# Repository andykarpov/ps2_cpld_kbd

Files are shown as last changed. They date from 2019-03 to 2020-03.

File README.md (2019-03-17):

# PS/2 AVR CPLD keyboard adapter

PS/2 keyboard adapter for ZX Spectrum on Atmega328 + EPM7128STC100.
Designed to be connected directly instead of a mechanical keyboard.

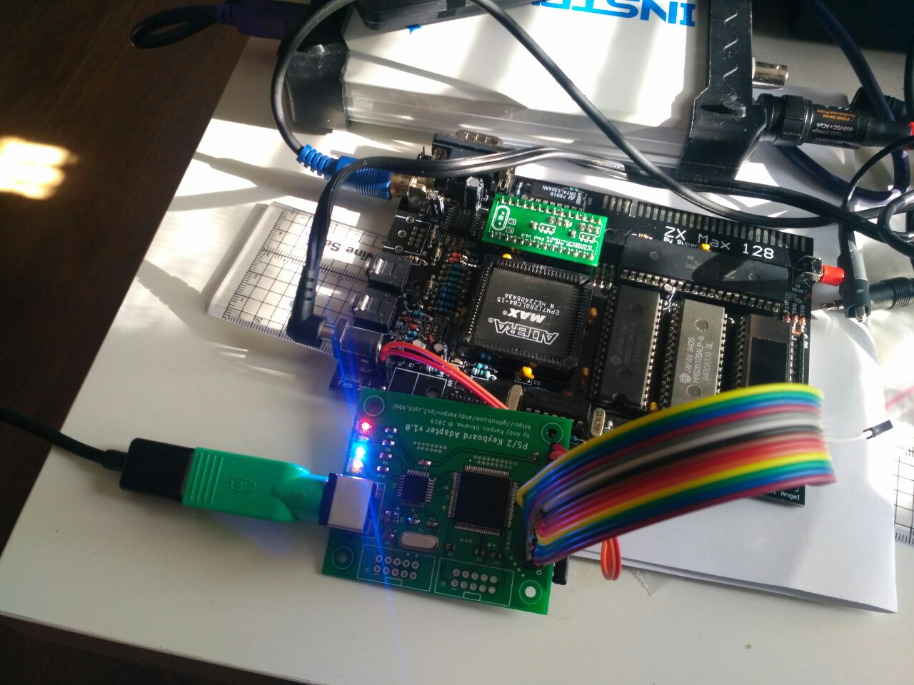
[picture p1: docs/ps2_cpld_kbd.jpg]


Based on the idea of the Yet another ZX-Spectrum AT Keyboard Interface http://www.jrok.com/project/speckey/spec_key.html

## How to program

### Programming Atmega328p
1. disconnect EPM7128 from the power source by disconnecting jumper JP1
2. avrdude -p atmega328p -c USBasp -U flash:w:avr_kbd_mega328p.hex -U lfuse:w:0xbf:m -U hfuse:w:0xda:m -U efuse:w:0xfd:m
3. short JP1

### Programming EPM7128S
use quartus programmer to flash cpld_kbd.pof

## Available hotkeys
1. Ctrl+Alt+Del generate a short negative pulse on O_RESET pin. It's nice to connect this signal to N_RESET of your ZX Spectrum
2. Ctrl+Alt+Backspace produce a controller internal reset needed for some reason
3. F2 generate a short negative pulse on O_MAGICK pin. If you have a BDI controller then you have to connect this signal to magick button.
4. Scroll Lock switch on / off the O_TURBO signal
5. PrintScreen switch on / off the O_SPECIAL signal

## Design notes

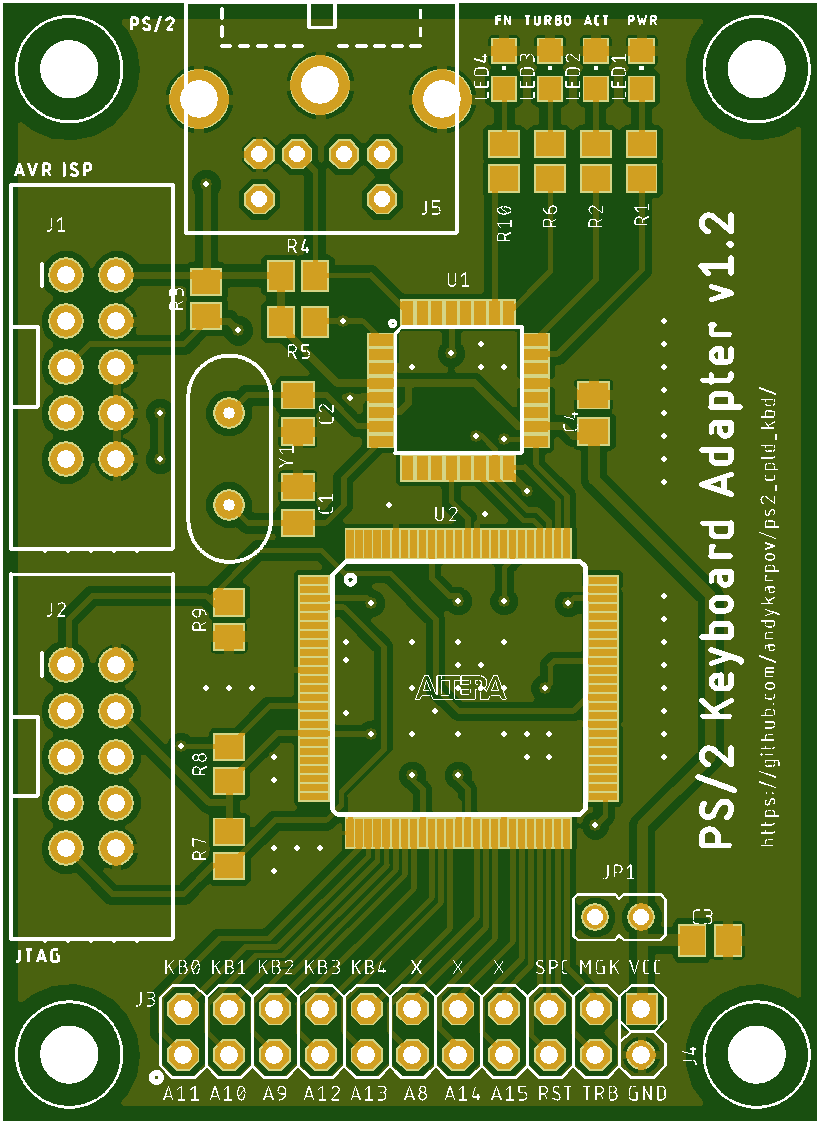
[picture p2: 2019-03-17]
docs/ps2_cpld_kbd_1.2.png

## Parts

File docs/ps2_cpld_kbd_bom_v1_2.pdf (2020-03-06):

Sheet1

Component | Quantity | Package | Value
U1 | 1 | QFP-32 | Atmega328P-AU
U2 | 1 | TQFP-100 | EPM7128STC100-15N
Y1 | 1 | HC-49S | 16.000 MHz crysyal
R3,R11-R18 | 9 | R 0805 | 10k
R1,R2,R6,R10 | 4 | R 0805 | 470 Ohm
R7,R8,R9 | 3 | R 0805 | 1k
R4,R5 | 2 | R 0805 | 4k7
C1,C2 | 2 | C 0805 | 22pF
C3-C8 | 6 | C 0805 | 100nF
LED1-LED4 | 4 | LED 0805 | red,green,yellow,blue,etc
J5 | 1 | Mini-DIN6 (ps/2 female socket)
J1,J2 | 2 | 10p IDC male Shrouded Header
J3 | 1 | 20p Pin Header (0.1”)
J4, JP1 | 2 | 2p Pin Header (0.1”)

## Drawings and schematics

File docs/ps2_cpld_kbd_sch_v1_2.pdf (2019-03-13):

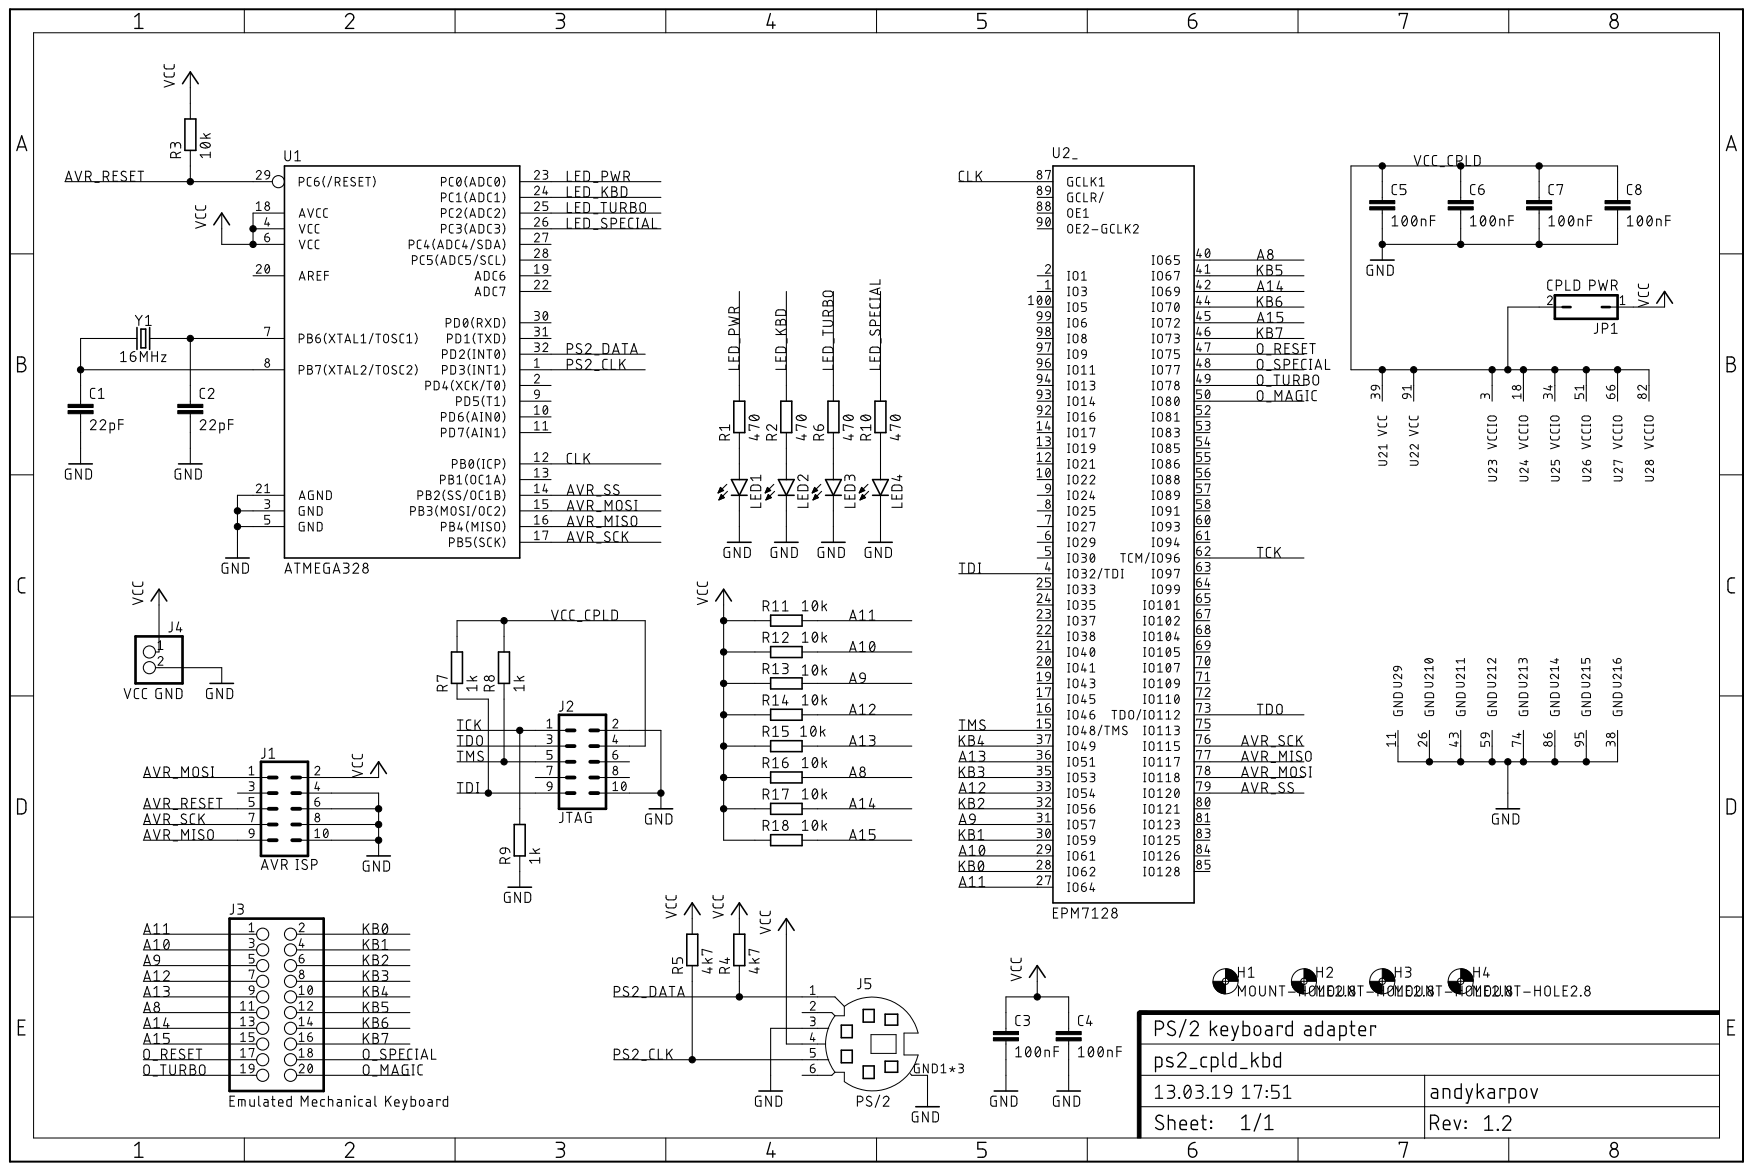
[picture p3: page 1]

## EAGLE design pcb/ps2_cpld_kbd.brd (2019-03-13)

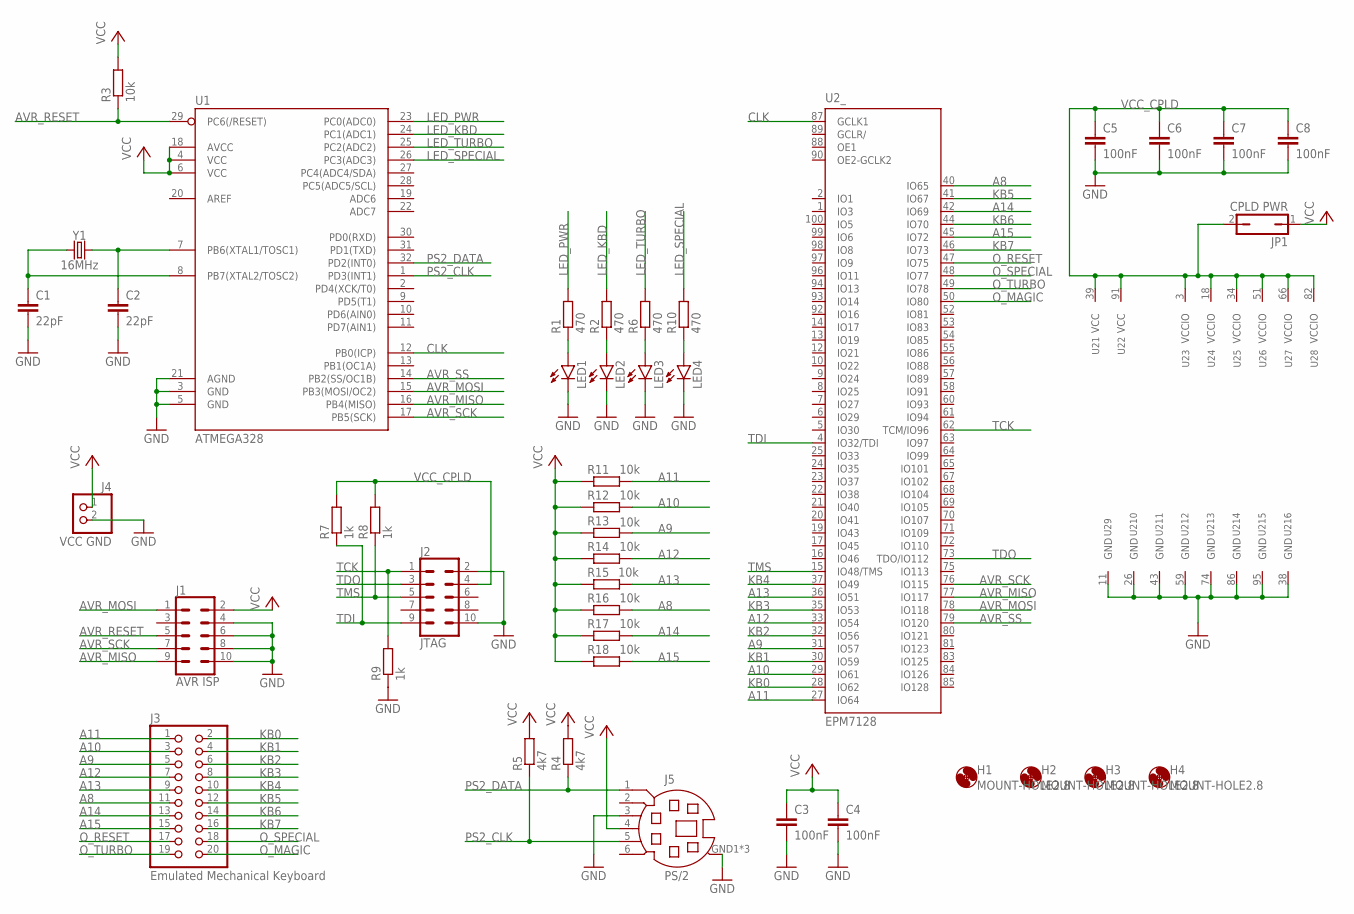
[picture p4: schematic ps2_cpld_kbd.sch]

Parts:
C1, C2: 22pF; C0805K
C3, C4, C5, C6, C7, C8: 100nF; C0805K
H1, H2, H3, H4: MOUNT-HOLE2.8; 2,8
J1: AVR ISP; 2X5-SHROUDED_LOCK
J2: JTAG; 2X5-SHROUDED_LOCK
J3: Emulated Mechanical Keyboard; 2X10
J4: VCC GND; 1X02
J5: PS/2; MDIN06SS
JP1: CPLD PWR; JP1
LED1, LED2, LED3, LED4: LEDCHIPLED_0805; CHIPLED_0805
R1, R2, R6, R10: 470; R0805
R3, R11, R12, R13, R14, R15, R16, R17, R18: 10k; R0805
R4, R5: 4k7; R0805
R7, R8, R9: 1k; R0805
U1: ATMEGA328; TQFP32-08
U2: EPM7128; TQFP100
Y1: 16MHz; HC49US

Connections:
A8: J3.11, R16.2, U2.40 (IO65)
A9: J3.5, R13.2, U2.31 (IO57)
A10: J3.3, R12.2, U2.29 (IO61)
A11: J3.1, R11.2, U2.27 (IO64)
A12: J3.7, R14.2, U2.33 (IO54)
A13: J3.9, R15.2, U2.36 (IO51)
A14: J3.13, R17.2, U2.42 (IO69)
A15: J3.15, R18.2, U2.45 (IO72)
AVR_MISO: J1.9, U1.16 (PB4(MISO)), U2.77 (IO117)
AVR_MOSI: J1.1, U1.15 (PB3(MOSI/OC2)), U2.78 (IO118)
AVR_RESET: J1.5, R3.1, U1.29 (PC6(/RESET))
AVR_SCK: J1.7, U1.17 (PB5(SCK)), U2.76 (IO115)
AVR_SS: U1.14 (PB2(SS/OC1B)), U2.79 (IO120)
CLK: U1.12 (PB0(ICP)), U2.87 (GCLK1)
GND: C1.2, C2.2, C3.2, C4.2, C5.2, C6.2, C7.2, C8.2, J1.4, J1.6, J1.8, J1.10, J2.2, J2.10, J4.2, J5.3, J5.GND1 (GND), J5.GND2 (GND), J5.GND3 (GND), LED1.C, LED2.C, LED3.C, LED4.C, R9.1, U1.3 (GND), U1.5 (GND), U1.21 (AGND), U2.11 (GND), U2.26 (GND), U2.38 (GND), U2.43 (GND), U2.59 (GND), U2.74 (GND), U2.86 (GND), U2.95 (GND)
KB0: J3.2, U2.28 (IO62)
KB1: J3.4, U2.30 (IO59)
KB2: J3.6, U2.32 (IO56)
KB3: J3.8, U2.35 (IO53)
KB4: J3.10, U2.37 (IO49)
KB5: J3.12, U2.41 (IO67)
KB6: J3.14, U2.44 (IO70)
KB7: J3.16, U2.46 (IO73)
LED_KBD: R2.2, U1.24 (PC1(ADC1))
LED_PWR: R1.2, U1.23 (PC0(ADC0))
LED_SPECIAL: R10.2, U1.26 (PC3(ADC3))
LED_TURBO: R6.2, U1.25 (PC2(ADC2))
unnamed: LED3.A, R6.1
unnamed: LED2.A, R2.1
unnamed: LED1.A, R1.1
unnamed: C2.1, U1.7 (PB6(XTAL1/TOSC1)), Y1.2
unnamed: C1.1, U1.8 (PB7(XTAL2/TOSC2)), Y1.1
unnamed: LED4.A, R10.1
O_MAGIC: J3.20, U2.50 (IO80)
O_RESET: J3.17, U2.47 (IO75)
O_SPECIAL: J3.18, U2.48 (IO77)
O_TURBO: J3.19, U2.49 (IO78)
PS2_CLK: J5.5, R5.1, U1.1 (PD3(INT1))
PS2_DATA: J5.1, R4.1, U1.32 (PD2(INT0))
TCK: J2.1, R9.2, U2.62 (TCM/IO96)
TDI: J2.9, R7.1, U2.4 (IO32/TDI)
TDO: J2.3, U2.73 (TDO/IO112)
TMS: J2.5, R8.1, U2.15 (IO48/TMS)
VCC: C3.1, C4.1, J1.2, J4.1, J5.4, JP1.1, R3.2, R4.2, R5.2, R11.1, R12.1, R13.1, R14.1, R15.1, R16.1, R17.1, R18.1, U1.4 (VCC), U1.6 (VCC), U1.18 (AVCC)
VCC_CPLD: C5.1, C6.1, C7.1, C8.1, J2.4, JP1.2, R7.2, R8.2, U2.3 (VCCIO), U2.18 (VCCIO), U2.34 (VCCIO), U2.39 (VCC), U2.51 (VCCIO), U2.66 (VCCIO), U2.82 (VCCIO), U2.91 (VCC)

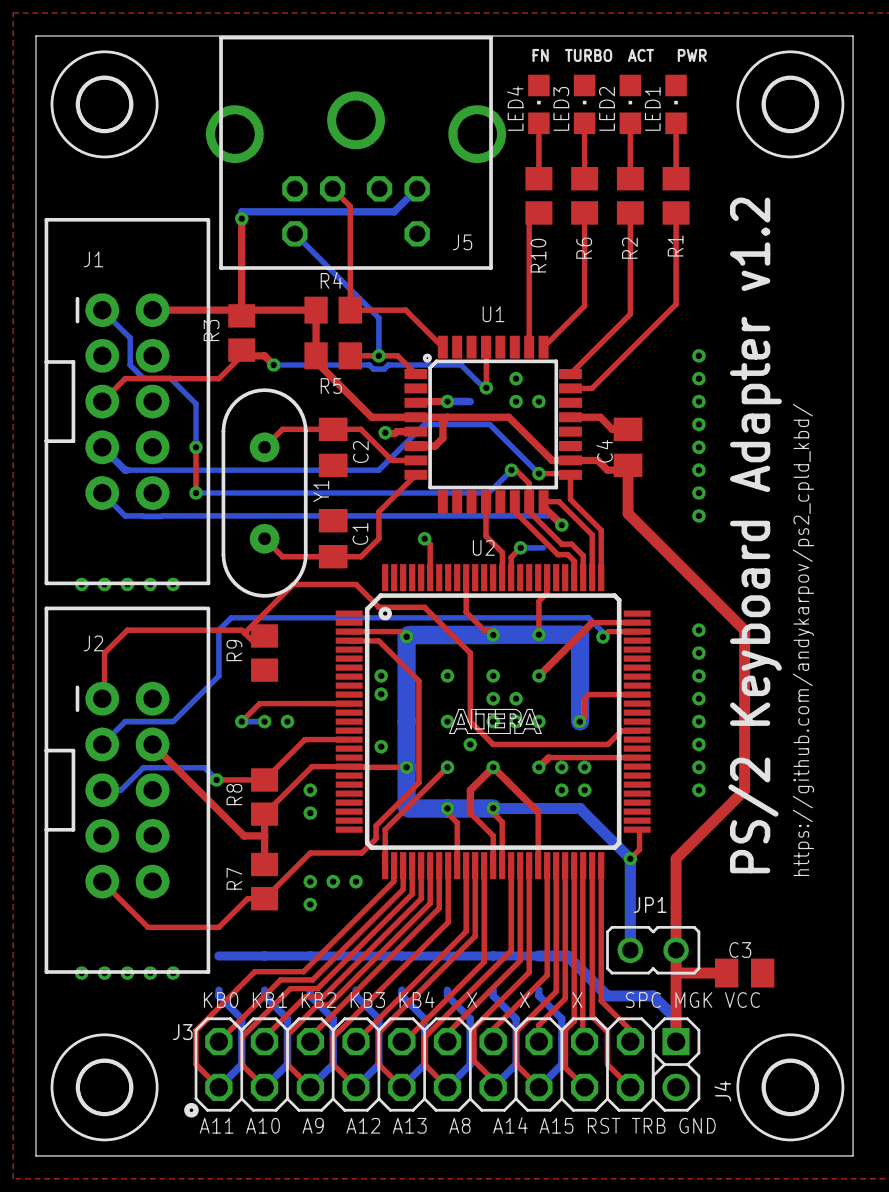
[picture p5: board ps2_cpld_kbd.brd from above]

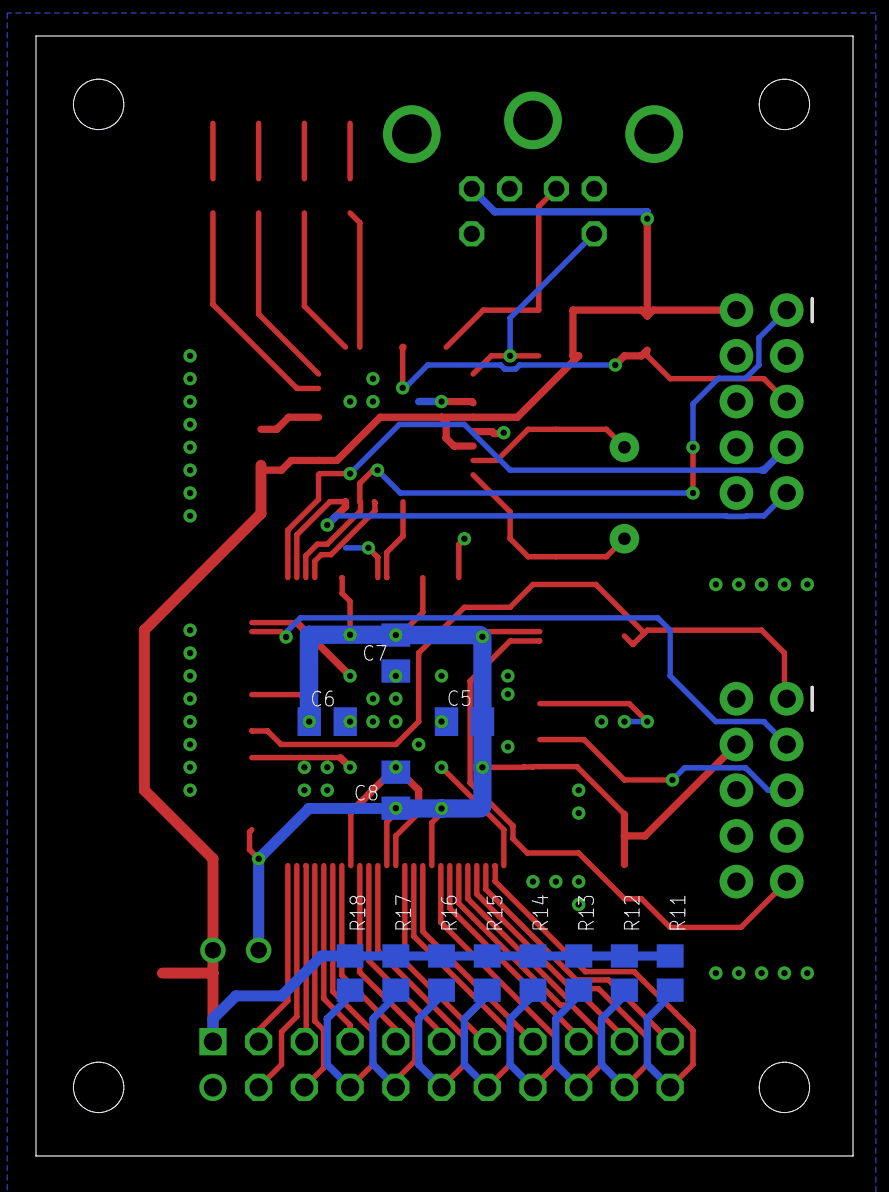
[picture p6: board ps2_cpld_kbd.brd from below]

Board: 2 copper layers, 45.4 x 62.2 mm, 43 parts (12 on the bottom side), 45 nets.

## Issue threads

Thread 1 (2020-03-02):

BoM list please

jduraes, 2020-03-02:
Hi Andy,

Any chance you could please publish a Bill of Materials for the components used? I know I could decipher them, but I'm learning and didn't want to make mistakes. Thanks.

andykarpov, 2020-03-06:
Ok, will try to do that

andykarpov, 2020-03-06:
Done: https://github.com/andykarpov/ps2_cpld_kbd/raw/master/docs/ps2_cpld_kbd_bom_v1_2.pdf

Closed 2020-03-06.

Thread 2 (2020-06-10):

Powering up

mr-mosh, 2020-06-10:
@andykarpov , sorry to trouble you this way, but I don't have any other means to contact you.

I have now built the adapter with the v1.2 files, and I have a few questions please:

- Is it normal for the Altera Max to sometimes fail on programming? I have never programmed an FPGA before. In the end I succeeded, but it took a few attempts - like, literally just pressing "Program" a few times until it worked.
- What's the best way to test the adapter, before I plug it into my 48k Spectrum? Cross check the matrix while pressing keys on the PS/2 keyboard?
- Am I right in saying that JP1 is just an on/off switch for the CPLD?
- Should I power the adapter using J4 (VCC/GND)?
- What's the right voltage to use? 3.3v seems to work, but a default 48k Spectrum only has 5v (well, and -5v, 9v and 12v...)
- Any idea how to power it from a Spectrum 48k? Do I just pull some VCC from anywhere, or should it be tied into something in particular?
- In your case you've used a ZX Max 128 as an example, so I don't have a reference to go for. For example, you have wires from JP1 to the ZX Max - does the ZX Max switch it on by some function on it? Or is it actually powering the adapter using those wires?

Many thanks - I had fun building it. Now hoping to actually use it! :-)

P.S.: is there a way for me to get the ZX Max 128? I would love to build that my next project. Cheers.

andykarpov, 2020-06-10:
@mr-mosh, congratulations and thanks for a lot of questions! :)
Will try to answer them:
1) Altera sometimes fails on programming - i think it's not very good, probably depends on the power quality applied to the altera while programming it. Did you applied 5V to the adapter while programmming it?
2) No ideas about the best way to test the adapter, really. You can apply power to it and connect a ps/2 keyboard and see if leds are blinked while pressing the keys, etc. The keyboard data will be available on the KB0-KB4 lines only in case one of the A8-A15 lines is LOW and some keys is pressed. So, i think you can try to ground some address pin and test it this way.
3) Yes, JP1 is just to on/off the power from the CPLD. Because it's hard connected to the AVR via the SPI, the same pins used to to program the AVR.
4) Yes, you need to power your adapter via J4 (VCC/GND). There is should be 5V DC.
5) You can grab 5V and GND somewhere from the Speccy 48k board, like from the CPU, for example :)
6) There was no JP1 on the v1.0 of the adapter, so it's unclear a bit what is your question about the ZX Max ;) Probably you mean a J4 ? So then - yes, it's just for powering the adapter by that connector.
7) Anyway, if the altera and atmega was successfully flashed - feel free to try it with the real hardware.

P.S. I think you can check on eBay, on the speccy.pl forum or on the chipkin.ru website for the clean PCB of ZX Max 128. For example: https://chipkin.ru/product/pechatnaya-plata-zx-max128/

Good luck, @mr-mosh! You can PM me to andy.karpov+github at gmail.com

andykarpov, 2020-06-17:
@mr-mosh, any news/questions ?

mr-mosh, 2020-06-17:
Hi @andykarpov ,

I do have them, but have been leaving some time before my next barrage of questions. :-)

Just kidding. I had to focus on something else and didn't have the will to get back to it.

This because it didn't quite work. All I was getting when pressing some of the keys, mostly on the left side of the keyboard, was the character "c" being registered on the Spectrum, and with about some 200ms delay (is that the expect lag?).

I don't know if the problem is on the adapter itself, or actually on the Spectrum. This Issue 4B board was in really bad shape and I had to reconstruct a lot of the traces to the CPU, memory, ULA, and also had to replace some resistors and diodes. I have not yet recapped it either.

But there are a lot of things that need re-checking, which is why I said I need more time to debug it in detail. I also made some mistakes on the adapter. I initially used some very old solder, and that didn't flow properly over the CPLD, and then I made a nasty job cleaning it up, damaging some pads in the process. The EPM7128 I've used also didn't have pin 1 on it, although I don't think that matters, as pin 1 on your schematic isn't connected to anything - right?

I've ordered some new EPM7128s to try it on a new, fresh PCB. Coincidently, they have just arrived today. Question: does it matter that they're 100ns instead of the 150ns you've used? Usually faster is better, right? Famous last words... :-)

I'm going to get back to it on Friday, and I think I'll first try the adapter with a known-good Spectrum - I have a "good" Issue 4S where I have also used pins for the keyboard connectors, so I can try it there. Then I'll know if the problem is with the Spectrum or the adapter. If the adapter, I'll build a new one; if the Spectrum, well, I'll have a lot of fun troubleshooting on that front...

Following on from our previous stable 5v talk, I've used a good 5v source and was still have random success re-programming the CPLD: sometimes it worked, sometimes it didn't. So I'm not even sure if the CPLD was programmed successfully or not.

Anyway, I'll look at it again on Friday and let you know.

Cheers.

andykarpov, 2020-06-17:
Hmm, well, something seems wrong. 200ms delay is not the expected thing at all ;)

How did you flashed the AVR ? Does the fuse bits are flashed ok ? Because i used it's feature CKOUT to out a 16MHz clock to the CPLD.

Altera's PIN_1 is ok to be unconnected ;)

100ns / 150ns - does not matter, they all should work.

Does the A and KB lines are connected properly to the speccy?

Regarding the partial success with CPLD programming - that's really strange, i think it's because of bad soldering of some I/O power lines on it.

Anyway - good luck with rework on a new PCB with a new solder ;)

P.S. Did you tried it with another keyboard?

IvanKoc87, 2022-02-09:
Можно заменить атмегу 328 на атмегу 8 ?

andykarpov, 2022-02-09:
> Можно заменить атмегу 328 на атмегу 8 ?

нельзя, она не умеет делать CKOUT (клок для тактирования CPLD).
можно попробовать заменить на atmega 168.

IvanKoc87, 2022-02-09:
можно попробовать заменить на atmega 168.
Смысла нет у них цена одинакова.

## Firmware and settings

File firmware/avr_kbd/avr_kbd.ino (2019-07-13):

/*
 * AVR keyboard firmware for ps2_cpld_kbd project
 * 
 * Designed to build on Arduino IDE.
 * 
 * @author Andy Karpov <andy.karpov@gmail.com>
 * Ukraine, 2019
 */

#include "ps2.h"
#include "matrix.h"
#include "ps2_codes.h"
#include <EEPROM.h>
#include <SPI.h>

#define DEBUG_MODE 0

// ---- Pins for Atmega328
#define PIN_KBD_CLK 3 // PD2
#define PIN_KBD_DAT 2 // PD2

// hardware SPI
#define PIN_SS 10 // SPI slave select

#define LED_PWR A0
#define LED_KBD A1
#define LED_TURBO A2
#define LED_SPECIAL A3

#define EEPROM_TURBO_ADDRESS 0x00
#define EEPROM_SPECIAL_ADDRESS 0x01

#define EEPROM_VALUE_TRUE 10
#define EEPROM_VALUE_FALSE 20

PS2KeyRaw kbd;

bool matrix[ZX_MATRIX_FULL_SIZE]; // matrix of pressed keys + special keys to be transmitted on CPLD side by SPI protocol

bool blink_state = false;

bool is_turbo = false;
bool is_special = false;

unsigned long t = 0;  // current time
unsigned long tl = 0; // blink poll time
unsigned long te = 0; // eeprom store time

SPISettings settingsA(8000000, MSBFIRST, SPI_MODE0); // SPI transmission settings

// transform PS/2 scancodes into internal matrix of pressed keys
void fill_kbd_matrix(int sc)
{

  static bool is_up=false, is_e=false, is_e1=false;
  static bool is_ctrl=false, is_alt=false, is_del=false, is_bksp = false, is_shift = false, is_esc = false, is_ss_used = false, is_cs_used = false;

  // is extended scancode prefix
  if (sc == 0xE0) {
    is_e = 1;
    return;
  }

 if (sc == 0xE1) {
    is_e = 1;
    is_e1 = 1;
    return;
  }

  // is key released prefix
  if (sc == 0xF0 && !is_up) {
    is_up = 1;
    return;
  }

  int scancode = sc + ((is_e || is_e1) ? 0x100 : 0);

  is_ss_used = false;
  is_cs_used = false;

  switch (scancode) {
  
    // Shift -> CS for ZX
    case PS2_L_SHIFT: 
    case PS2_R_SHIFT:
      matrix[ZX_K_CS] = !is_up;
      is_shift = !is_up;
      break;

    // Ctrl -> SS for ZX
    case PS2_L_CTRL:
    case PS2_R_CTRL:
      matrix[ZX_K_SS] = !is_up;
      is_ctrl = !is_up;
      break;

    // Alt (L) -> SS+CS for ZX
    case PS2_L_ALT:
      matrix[ZX_K_SS] = !is_up;
      matrix[ZX_K_CS] = !is_up;
      is_alt = !is_up;
      is_cs_used = !is_up;
      break;

    // Alt (R) -> SS+CS for ZX
    case PS2_R_ALT:
      matrix[ZX_K_SS] = !is_up;
      matrix[ZX_K_CS] = !is_up;
      is_alt = !is_up;
      is_cs_used = !is_up;
      break;

    // Del -> SS+C for ZX
    case PS2_DELETE:
       matrix[ZX_K_SS] = !is_up;
       matrix[ZX_K_C] =  !is_up;
      is_del = !is_up;
    break;

    // Ins -> SS+A for ZX
    case PS2_INSERT:
       matrix[ZX_K_SS] = !is_up;
       matrix[ZX_K_A] =  !is_up;
    break;

    // Cursor -> CS + 5,6,7,8
    case PS2_UP:
      matrix[ZX_K_CS] = !is_up;
      matrix[ZX_K_7] = !is_up;
      is_cs_used = !is_up;
      break;
    case PS2_DOWN:
      matrix[ZX_K_CS] = !is_up;
      matrix[ZX_K_6] = !is_up;
      is_cs_used = !is_up;
      break;
    case PS2_LEFT:
      matrix[ZX_K_CS] = !is_up;
      matrix[ZX_K_5] = !is_up;
      is_cs_used = !is_up;
      break;
    case PS2_RIGHT:
      matrix[ZX_K_CS] = !is_up;
      matrix[ZX_K_8] = !is_up;
      is_cs_used = !is_up;
      break;

    // ESC -> CS+SPACE for ZX
    case PS2_ESC:
      matrix[ZX_K_CS] = !is_up;
      matrix[ZX_K_SP] = !is_up;
      is_cs_used = !is_up;
      is_esc = !is_up;
      break;

    // Backspace -> CS+0
    case PS2_BACKSPACE:
      matrix[ZX_K_CS] = !is_up;
      matrix[ZX_K_0] = !is_up;
      is_cs_used = !is_up;
      is_bksp = !is_up;
      break;

    // Enter
    case PS2_ENTER:
    case PS2_KP_ENTER:
      matrix[ZX_K_ENT] = !is_up;
      break;

    // Space
    case PS2_SPACE:
      matrix[ZX_K_SP] = !is_up;
      break;

    // Letters & numbers
    case PS2_A: matrix[ZX_K_A] = !is_up; break;
    case PS2_B: matrix[ZX_K_B] = !is_up; break;
    case PS2_C: matrix[ZX_K_C] = !is_up; break;
    case PS2_D: matrix[ZX_K_D] = !is_up; break;
    case PS2_E: matrix[ZX_K_E] = !is_up; break;
    case PS2_F: matrix[ZX_K_F] = !is_up; break;
    case PS2_G: matrix[ZX_K_G] = !is_up; break;
    case PS2_H: matrix[ZX_K_H] = !is_up; break;
    case PS2_I: matrix[ZX_K_I] = !is_up; break;
    case PS2_J: matrix[ZX_K_J] = !is_up; break;
    case PS2_K: matrix[ZX_K_K] = !is_up; break;
    case PS2_L: matrix[ZX_K_L] = !is_up; break;
    case PS2_M: matrix[ZX_K_M] = !is_up; break;
    case PS2_N: matrix[ZX_K_N] = !is_up; break;
    case PS2_O: matrix[ZX_K_O] = !is_up; break;
    case PS2_P: matrix[ZX_K_P] = !is_up; break;
    case PS2_Q: matrix[ZX_K_Q] = !is_up; break;
    case PS2_R: matrix[ZX_K_R] = !is_up; break;
    case PS2_S: matrix[ZX_K_S] = !is_up; break;
    case PS2_T: matrix[ZX_K_T] = !is_up; break;
    case PS2_U: matrix[ZX_K_U] = !is_up; break;
    case PS2_V: matrix[ZX_K_V] = !is_up; break;
    case PS2_W: matrix[ZX_K_W] = !is_up; break;
    case PS2_X: matrix[ZX_K_X] = !is_up; break;
    case PS2_Y: matrix[ZX_K_Y] = !is_up; break;
    case PS2_Z: matrix[ZX_K_Z] = !is_up; break;

    // digits
    case PS2_0: matrix[ZX_K_0] = !is_up; break;
    case PS2_1: matrix[ZX_K_1] = !is_up; break;
    case PS2_2: matrix[ZX_K_2] = !is_up; break;
    case PS2_3: matrix[ZX_K_3] = !is_up; break;
    case PS2_4: matrix[ZX_K_4] = !is_up; break;
    case PS2_5: matrix[ZX_K_5] = !is_up; break;
    case PS2_6: matrix[ZX_K_6] = !is_up; break;
    case PS2_7: matrix[ZX_K_7] = !is_up; break;
    case PS2_8: matrix[ZX_K_8] = !is_up; break;
    case PS2_9: matrix[ZX_K_9] = !is_up; break;

    // Keypad digits
    case PS2_KP_0: matrix[ZX_K_0] = !is_up; break;
    case PS2_KP_1: matrix[ZX_K_1] = !is_up; break;
    case PS2_KP_2: matrix[ZX_K_2] = !is_up; break;
    case PS2_KP_3: matrix[ZX_K_3] = !is_up; break;
    case PS2_KP_4: matrix[ZX_K_4] = !is_up; break;
    case PS2_KP_5: matrix[ZX_K_5] = !is_up; break;
    case PS2_KP_6: matrix[ZX_K_6] = !is_up; break;
    case PS2_KP_7: matrix[ZX_K_7] = !is_up; break;
    case PS2_KP_8: matrix[ZX_K_8] = !is_up; break;
    case PS2_KP_9: matrix[ZX_K_9] = !is_up; break;

    // '/" -> SS+P / SS+7
    case PS2_QUOTE:
      matrix[ZX_K_SS] = !is_up;
      matrix[is_shift ? ZX_K_P : ZX_K_7] = !is_up;
      is_ss_used = is_shift;
      break;

    // ,/< -> SS+N / SS+R
    case PS2_COMMA:
      matrix[ZX_K_SS] = !is_up;
      matrix[is_shift ? ZX_K_R : ZX_K_N] = !is_up;
      is_ss_used = is_shift;
      break;

    // ./> -> SS+M / SS+T
    case PS2_PERIOD:
    case PS2_KP_PERIOD:
      matrix[ZX_K_SS] = !is_up;
      matrix[is_shift ? ZX_K_T : ZX_K_M] = !is_up;
      is_ss_used = is_shift;
      break;

    // ;/: -> SS+O / SS+Z
    case PS2_SEMICOLON:
      matrix[ZX_K_SS] = !is_up;
      matrix[is_shift ? ZX_K_Z : ZX_K_O] = !is_up;
      is_ss_used = is_shift;
      break;

    // [,{ -> SS+Y / SS+F
    case PS2_L_BRACKET:
      if (!is_up) {
        send_macros(is_shift ? ZX_K_F : ZX_K_Y);
      }
      break;

    // ],} -> SS+U / SS+G
    case PS2_R_BRACKET:
      if (!is_up) {
        send_macros(is_shift ? ZX_K_G : ZX_K_U);
      }
      break;

    // /,? -> SS+V / SS+C
    case PS2_SLASH:
    case PS2_KP_SLASH:
      matrix[ZX_K_SS] = !is_up;
      matrix[is_shift ? ZX_K_C : ZX_K_V] = !is_up;
      is_ss_used = is_shift;
      break;

    // \,| -> SS+D / SS+S
    case PS2_BACK_SLASH:
      if (!is_up) {
        send_macros(is_shift ? ZX_K_S : ZX_K_D);
      }
      break;

    // =,+ -> SS+L / SS+K
    case PS2_EQUALS:
      matrix[ZX_K_SS] = !is_up;
      matrix[is_shift ? ZX_K_K : ZX_K_L] = !is_up;
      is_ss_used = is_shift;
      break;

    // -,_ -> SS+J / SS+0
    case PS2_MINUS:
      matrix[ZX_K_SS] = !is_up;
      matrix[is_shift ? ZX_K_0 : ZX_K_J] = !is_up;
      is_ss_used = is_shift;
      break;

    // `,~ -> SS+X / SS+A
    case PS2_ACCENT:
      if (is_shift and !is_up) {
        send_macros(is_shift ? ZX_K_A : ZX_K_X);
      }
      if (!is_shift) {
        matrix[ZX_K_SS] = !is_up;
        matrix[ZX_K_X] = !is_up;
        is_ss_used = is_shift;
      }
      break;

    // Keypad * -> SS+B
    case PS2_KP_STAR:
      matrix[ZX_K_SS] = !is_up;
      matrix[ZX_K_B] = !is_up;
      break;

    // Keypad - -> SS+J
    case PS2_KP_MINUS:
      matrix[ZX_K_SS] = !is_up;
      matrix[ZX_K_J] = !is_up;
      break;

    // Keypad + -> SS+K
    case PS2_KP_PLUS:
      matrix[ZX_K_SS] = !is_up;
      matrix[ZX_K_K] = !is_up;
      break;

    // Tab
    case PS2_TAB:
      matrix[ZX_K_CS] = !is_up;
      matrix[ZX_K_I] = !is_up;
      is_cs_used = !is_up;
      break;

    // CapsLock
    case PS2_CAPS:
      matrix[ZX_K_SS] = !is_up;
      matrix[ZX_K_CS] = !is_up;
      is_cs_used = !is_up;
      break;

    // PgUp -> CS+3 for ZX
    case PS2_PGUP:
      matrix[ZX_K_CS] = !is_up;
      matrix[ZX_K_3] = !is_up;
      is_cs_used = !is_up;
      break;

    // PgDn -> CS+4 for ZX
    case PS2_PGDN:
      matrix[ZX_K_CS] = !is_up;
      matrix[ZX_K_4] = !is_up;
      is_cs_used = !is_up;
      break;

    // Scroll Lock -> Turbo
    case PS2_SCROLL: 
      if (is_up) {
        is_turbo = !is_turbo;        
        eeprom_store_value(EEPROM_TURBO_ADDRESS, is_turbo);
        matrix[ZX_K_TURBO] = is_turbo;
      }
    break;

    // PrintScreen -> Special
    case PS2_PSCR1: 
      if (is_up) {
        is_special = !is_special;        
        eeprom_store_value(EEPROM_SPECIAL_ADDRESS, is_special);
        matrix[ZX_K_SPECIAL] = is_special;
      }
    break;

    // F2 -> Magick button
    case PS2_F2:
      if (is_up) {
        do_magick();
      }
    break;
  
  }

  if (is_ss_used and !is_cs_used) {
      matrix[ZX_K_CS] = false;
  }

  // Ctrl+Alt+Del -> RESET
  if (is_ctrl && is_alt && is_del) {
    is_ctrl = false;
    is_alt = false;
    is_del = false;
    is_shift = false;
    is_ss_used = false;
    is_cs_used = false;
    do_reset();
  }

  // Ctrl+Alt+Bksp -> REINIT controller
  if (is_ctrl && is_alt && is_bksp) {
      is_ctrl = false;
      is_alt = false;
      is_bksp = false;
      is_shift = false;
      is_ss_used = false;
      is_cs_used = false;
      clear_matrix(ZX_MATRIX_SIZE);
      matrix[ZX_K_RESET] = true;
      transmit_keyboard_matrix();
      matrix[ZX_K_S] = true;
      transmit_keyboard_matrix();
      delay(500);
      matrix[ZX_K_RESET] = false;
      transmit_keyboard_matrix();
      delay(500);
      matrix[ZX_K_S] = false;
  }

   // clear flags
   is_up = 0;
   if (is_e1) {
    is_e1 = 0;
   } else {
     is_e = 0;
   }
}

uint8_t get_matrix_byte(uint8_t pos)
{
  uint8_t result = 0;
  for (uint8_t i=0; i<8; i++) {
    uint8_t k = pos*8 + i;
    if (k < ZX_MATRIX_FULL_SIZE) {
      bitWrite(result, i, matrix[k]);
    }
  }
  return result;
}

void spi_send(uint8_t addr, uint8_t data) 
{
      SPI.beginTransaction(settingsA);
      digitalWrite(PIN_SS, LOW);
      uint8_t cmd = SPI.transfer(addr); // command (1...6)
      uint8_t res = SPI.transfer(data); // data byte
      digitalWrite(PIN_SS, HIGH);
      SPI.endTransaction();
}

// transmit keyboard matrix from AVR to CPLD side via SPI
void transmit_keyboard_matrix()
{
    uint8_t bytes = 6;
    for (uint8_t i=0; i<bytes; i++) {
      uint8_t data = get_matrix_byte(i);
      spi_send(i+1, data);
    }
}

// transmit keyboard macros (sequence of keyboard clicks) to emulate typing some special symbols [, ], {, }, ~, |, `
void send_macros(uint8_t pos)
{
  clear_matrix(ZX_MATRIX_SIZE);
  transmit_keyboard_matrix();
  delay(20);
  matrix[ZX_K_CS] = true;
  transmit_keyboard_matrix();
  delay(20);
  matrix[ZX_K_SS] = true;
  transmit_keyboard_matrix();
  delay(20);
  matrix[ZX_K_SS] = false;
  transmit_keyboard_matrix();
  delay(20);
  matrix[pos] = true;
  transmit_keyboard_matrix();
  delay(20);
  matrix[ZX_K_CS] = false;
  matrix[pos] = false;
  transmit_keyboard_matrix();
  delay(20);
}

void do_reset()
{
  clear_matrix(ZX_MATRIX_SIZE);
  matrix[ZX_K_RESET] = true;
  transmit_keyboard_matrix();
  delay(500);
  matrix[ZX_K_RESET] = false;
  transmit_keyboard_matrix();  
}

void do_magick()
{
  matrix[ZX_K_MAGICK] = true;
  transmit_keyboard_matrix();
  delay(500);
  matrix[ZX_K_MAGICK] = false;
  transmit_keyboard_matrix();
}

void clear_matrix(int clear_size)
{
    // all keys up
  for (int i=0; i<clear_size; i++) {
      matrix[i] = false;
  }
}

bool eeprom_restore_value(int addr, bool default_value)
{
  byte val;  
  val = EEPROM.read(addr);
  if ((val == EEPROM_VALUE_TRUE) || (val == EEPROM_VALUE_FALSE)) {
    return (val == EEPROM_VALUE_TRUE) ? true : false;
  } else {
    EEPROM.update(addr, (default_value ? EEPROM_VALUE_TRUE : EEPROM_VALUE_FALSE));
    return default_value;
  }
}

void eeprom_store_value(int addr, bool value)
{
  byte val = (value ? EEPROM_VALUE_TRUE : EEPROM_VALUE_FALSE);
  EEPROM.update(addr, val);
}

void eeprom_restore_values()
{
  is_turbo = eeprom_restore_value(EEPROM_TURBO_ADDRESS, is_turbo);
  is_special = eeprom_restore_value(EEPROM_SPECIAL_ADDRESS, is_special);
  matrix[ZX_K_TURBO] = is_turbo;
  matrix[ZX_K_SPECIAL] = is_special;
}

void eeprom_store_values()
{
  eeprom_store_value(EEPROM_TURBO_ADDRESS, is_turbo);
  eeprom_store_value(EEPROM_SPECIAL_ADDRESS, is_special);
}

// initial setup
void setup()
{
  Serial.begin(115200);
  Serial.flush();
  SPI.begin();

  pinMode(PIN_SS, OUTPUT);
  digitalWrite(PIN_SS, HIGH);

  pinMode(LED_PWR, OUTPUT);
  pinMode(LED_KBD, OUTPUT);
  pinMode(LED_TURBO, OUTPUT);
  pinMode(LED_SPECIAL, OUTPUT);
  
  digitalWrite(LED_PWR, HIGH);
  digitalWrite(LED_KBD, HIGH);
  digitalWrite(LED_TURBO, LOW);
  digitalWrite(LED_SPECIAL, LOW);

  // ps/2

  pinMode(PIN_KBD_CLK, INPUT_PULLUP);
  pinMode(PIN_KBD_DAT, INPUT_PULLUP);

  // zx signals (output)

  // clear full matrix
  clear_matrix(ZX_MATRIX_FULL_SIZE);

  // restore saved modes from EEPROM
  eeprom_restore_values();

  digitalWrite(LED_TURBO, is_turbo ? HIGH : LOW);
  digitalWrite(LED_SPECIAL, is_special ? HIGH: LOW);

Serial.println(F("ZX PS/2 Keyboard controller v1.0"));

#if DEBUG_MODE
  Serial.println(F("Reset on boot..."));
#endif

  do_reset();

#if DEBUG_MODE
  Serial.println(F("done"));
  Serial.println(F("Keyboard init..."));
#endif

  kbd.begin(PIN_KBD_DAT, PIN_KBD_CLK);

#if DEBUG_MODE
  Serial.println(F("done"));
#endif

  digitalWrite(LED_KBD, LOW);
  
}


// main loop
void loop()
{
  unsigned long n = millis();
  
  if (kbd.available()) {
    int c = kbd.read();
    blink_state = true;
    tl = n;
    digitalWrite(LED_KBD, HIGH);
#if DEBUG_MODE    
    Serial.print(F("Scancode: "));
    Serial.println(c, HEX);
#endif
    fill_kbd_matrix(c);
  }

  // transmit kbd always
  transmit_keyboard_matrix();


  // update leds
  if (n - tl >= 200) {
    digitalWrite(LED_KBD, LOW);
    blink_state = false;

    digitalWrite(LED_TURBO, is_turbo ? HIGH : LOW);
    digitalWrite(LED_SPECIAL, is_special ? HIGH: LOW);
    
  }
}

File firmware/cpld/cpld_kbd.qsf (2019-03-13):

# -------------------------------------------------------------------------- #
#
# Copyright (C) 1991-2013 Altera Corporation
# Your use of Altera Corporation's design tools, logic functions 
# and other software and tools, and its AMPP partner logic 
# functions, and any output files from any of the foregoing 
# (including device programming or simulation files), and any 
# associated documentation or information are expressly subject 
# to the terms and conditions of the Altera Program License 
# Subscription Agreement, Altera MegaCore Function License 
# Agreement, or other applicable license agreement, including, 
# without limitation, that your use is for the sole purpose of 
# programming logic devices manufactured by Altera and sold by 
# Altera or its authorized distributors.  Please refer to the 
# applicable agreement for further details.
#
# -------------------------------------------------------------------------- #
#
# Quartus II 32-bit
# Version 13.1.0 Build 162 10/23/2013 SJ Web Edition
# Date created = 14:53:04  января 06, 2019
#
# -------------------------------------------------------------------------- #
#
# Notes:
#
# 1) The default values for assignments are stored in the file:
#		cpld_kbd_assignment_defaults.qdf
#    If this file doesn't exist, see file:
#		assignment_defaults.qdf
#
# 2) Altera recommends that you do not modify this file. This
#    file is updated automatically by the Quartus II software
#    and any changes you make may be lost or overwritten.
#
# -------------------------------------------------------------------------- #


set_global_assignment -name TOP_LEVEL_ENTITY cpld_kbd
set_global_assignment -name VHDL_FILE spi_slave.vhd
set_global_assignment -name VHDL_FILE cpld_kbd.vhd

set_location_assignment PIN_87 -to CLK
set_location_assignment PIN_37 -to KB[4]
set_location_assignment PIN_35 -to KB[3]
set_location_assignment PIN_32 -to KB[2]
set_location_assignment PIN_30 -to KB[1]
set_location_assignment PIN_28 -to KB[0]
set_location_assignment PIN_36 -to A[13]
set_location_assignment PIN_33 -to A[12]
set_location_assignment PIN_31 -to A[9]
set_location_assignment PIN_29 -to A[10]
set_location_assignment PIN_27 -to A[11]
set_location_assignment PIN_40 -to A[8]
set_location_assignment PIN_42 -to A[14]
set_location_assignment PIN_45 -to A[15]
set_location_assignment PIN_77 -to AVR_MISO
set_location_assignment PIN_78 -to AVR_MOSI
set_location_assignment PIN_76 -to AVR_SCK
set_location_assignment PIN_79 -to AVR_SS
set_location_assignment PIN_50 -to O_MAGICK
set_location_assignment PIN_49 -to O_TURBO
set_location_assignment PIN_48 -to O_SPECIAL
set_location_assignment PIN_47 -to O_RESET


set_global_assignment -name FAMILY MAX7000S
set_global_assignment -name DEVICE "EPM7128STC100-15"
set_global_assignment -name ORIGINAL_QUARTUS_VERSION "13.0 SP1"
set_global_assignment -name PROJECT_CREATION_TIME_DATE "11:31:59  SEPTEMBER 25, 2017"
set_global_assignment -name LAST_QUARTUS_VERSION "13.0 SP1"
set_global_assignment -name DEVICE_FILTER_PIN_COUNT 100
set_global_assignment -name ERROR_CHECK_FREQUENCY_DIVISOR "-1"
set_global_assignment -name EDA_SIMULATION_TOOL "ModelSim-Altera (VHDL)"
set_global_assignment -name EDA_OUTPUT_DATA_FORMAT VHDL -section_id eda_simulation
set_global_assignment -name MAX7000_DEVICE_IO_STANDARD TTL

set_global_assignment -name FMAX_REQUIREMENT "16 MHz"
set_global_assignment -name FMAX_REQUIREMENT "16 MHz" -section_id CLK
set_global_assignment -name MAX7000_OPTIMIZATION_TECHNIQUE BALANCED
set_global_assignment -name AUTO_LCELL_INSERTION ON
set_global_assignment -name OPTIMIZE_HOLD_TIMING OFF
set_global_assignment -name AUTO_GLOBAL_CLOCK_MAX ON
set_global_assignment -name AUTO_GLOBAL_OE_MAX ON
set_global_assignment -name MAX_AUTO_GLOBAL_REGISTER_CONTROLS ON
set_instance_assignment -name CLOCK_SETTINGS CLK -to CLK
set_global_assignment -name FIT_ONLY_ONE_ATTEMPT OFF
set_global_assignment -name SIMULATION_MODE FUNCTIONAL
set_global_assignment -name RESERVE_ALL_UNUSED_PINS_NO_OUTPUT_GND "AS INPUT TRI-STATED"
set_global_assignment -name OPTIMIZE_IOC_REGISTER_PLACEMENT_FOR_TIMING NORMAL
set_global_assignment -name AUTO_TURBO_BIT AUTO
set_global_assignment -name REMOVE_DUPLICATE_REGISTERS ON
set_global_assignment -name AUTO_RESOURCE_SHARING ON
set_global_assignment -name STRATIXII_OPTIMIZATION_TECHNIQUE AREA
set_global_assignment -name CYCLONE_OPTIMIZATION_TECHNIQUE AREA
set_global_assignment -name STRATIX_OPTIMIZATION_TECHNIQUE AREA
set_global_assignment -name MAXII_OPTIMIZATION_TECHNIQUE AREA
set_global_assignment -name APEX20K_OPTIMIZATION_TECHNIQUE AREA
set_global_assignment -name STATE_MACHINE_PROCESSING "MINIMAL BITS"
set_global_assignment -name MAX7000_FANIN_PER_CELL 100
set_global_assignment -name DO_MIN_ANALYSIS OFF
set_global_assignment -name CUT_OFF_PATHS_BETWEEN_CLOCK_DOMAINS ON
set_global_assignment -name CUT_OFF_READ_DURING_WRITE_PATHS ON
set_global_assignment -name CUT_OFF_IO_PIN_FEEDBACK ON
set_global_assignment -name BLOCK_DESIGN_NAMING MAXPLUSII
set_global_assignment -name MAX7000_PARALLEL_EXPANDER_CHAIN_LENGTH 2
set_global_assignment -name SUPPRESS_REG_MINIMIZATION_MSG ON
set_global_assignment -name ENABLE_DRC_SETTINGS ON


set_global_assignment -name SYNTH_TIMING_DRIVEN_SYNTHESIS OFF
set_global_assignment -name OPTIMIZE_MULTI_CORNER_TIMING ON
set_global_assignment -name FITTER_EFFORT "STANDARD FIT"
set_global_assignment -name ALM_REGISTER_PACKING_EFFORT MEDIUM
set_global_assignment -name ECO_OPTIMIZE_TIMING OFF
set_global_assignment -name ECO_REGENERATE_REPORT OFF
set_global_assignment -name SLOW_SLEW_RATE OFF
set_global_assignment -name FORCE_FITTER_TO_AVOID_PERIPHERY_PLACEMENT_WARNINGS OFF


set_location_assignment PIN_46 -to O_CLK
set_location_assignment PIN_44 -to O_TEST
set_location_assignment PIN_41 -to O_DEBUG

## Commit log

2019-03-05 Added eagle sources and gerbers
    [ps2_cpld_kbd.brd, ps2_cpld_kbd.sch]
2019-03-13 fixed ps2 pin mapping
    [avr_kbd.ino]
2019-03-13 fixed ps/2 signal names, fixed github page url
    [ps2_cpld_kbd.brd, ps2_cpld_kbd.sch]
2019-03-13 updated schamatics and board v1.1
    [ps2_cpld_kbd.brd, ps2_cpld_kbd.sch]
2019-03-13 pcb gerbers v1.1
2019-03-13 new board v1.2 with fixes
    [ps2_cpld_kbd.brd, ps2_cpld_kbd.sch]
2019-03-13 added schematic diagram
2019-03-14 fixed bugs with external signals O_RESET & co
    [avr_kbd.ino]
2019-03-17 pcb photo v1.2
2019-03-18 added legacy gerbers (seed fusion cam job)
2019-07-13 fixed issue with shift special keys
    [avr_kbd.ino]
2020-03-06 added BOM

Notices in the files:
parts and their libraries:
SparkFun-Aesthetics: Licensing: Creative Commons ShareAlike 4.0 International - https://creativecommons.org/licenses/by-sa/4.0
